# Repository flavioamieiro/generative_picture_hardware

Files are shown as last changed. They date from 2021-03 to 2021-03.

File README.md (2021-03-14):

This repository includes the design files for the hardware of the
Generative Picture project (this name will probably change). The
schematics and PCB layout are done in Kicad and all extra libraries
necessary to edit the project should be included here. If you find any
issues, please let me know.

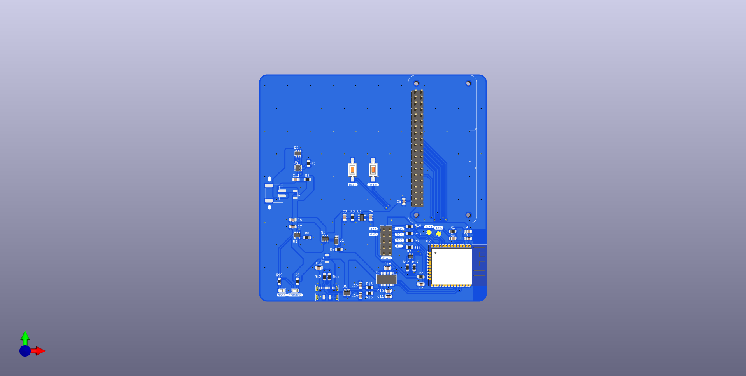
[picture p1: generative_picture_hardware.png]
generative picture board


This source describes Open Hardware and is licensed under the
CERN-OHL-S v2.  You may redistribute and modify this source and make
products using it under the terms of the CERN-OHL-S v2
(https://ohwr.org/cern_ohl_s_v2.txt).

This source is distributed WITHOUT ANY EXPRESS OR IMPLIED WARRANTY,
INCLUDING OF MERCHANTABILITY, SATISFACTORY QUALITY AND FITNESS FOR A
PARTICULAR PURPOSE. Please see the CERN-OHL-S v2 for applicable
conditions.

Source location:
https://github.com/flavioamieiro/generative_picture_hardware

As per CERN-OHL-S v2 section 4, should You produce hardware based on
this source, You must where practicable maintain the Source Location
visible on the external case of the Gizmo or other products you make
using this source.

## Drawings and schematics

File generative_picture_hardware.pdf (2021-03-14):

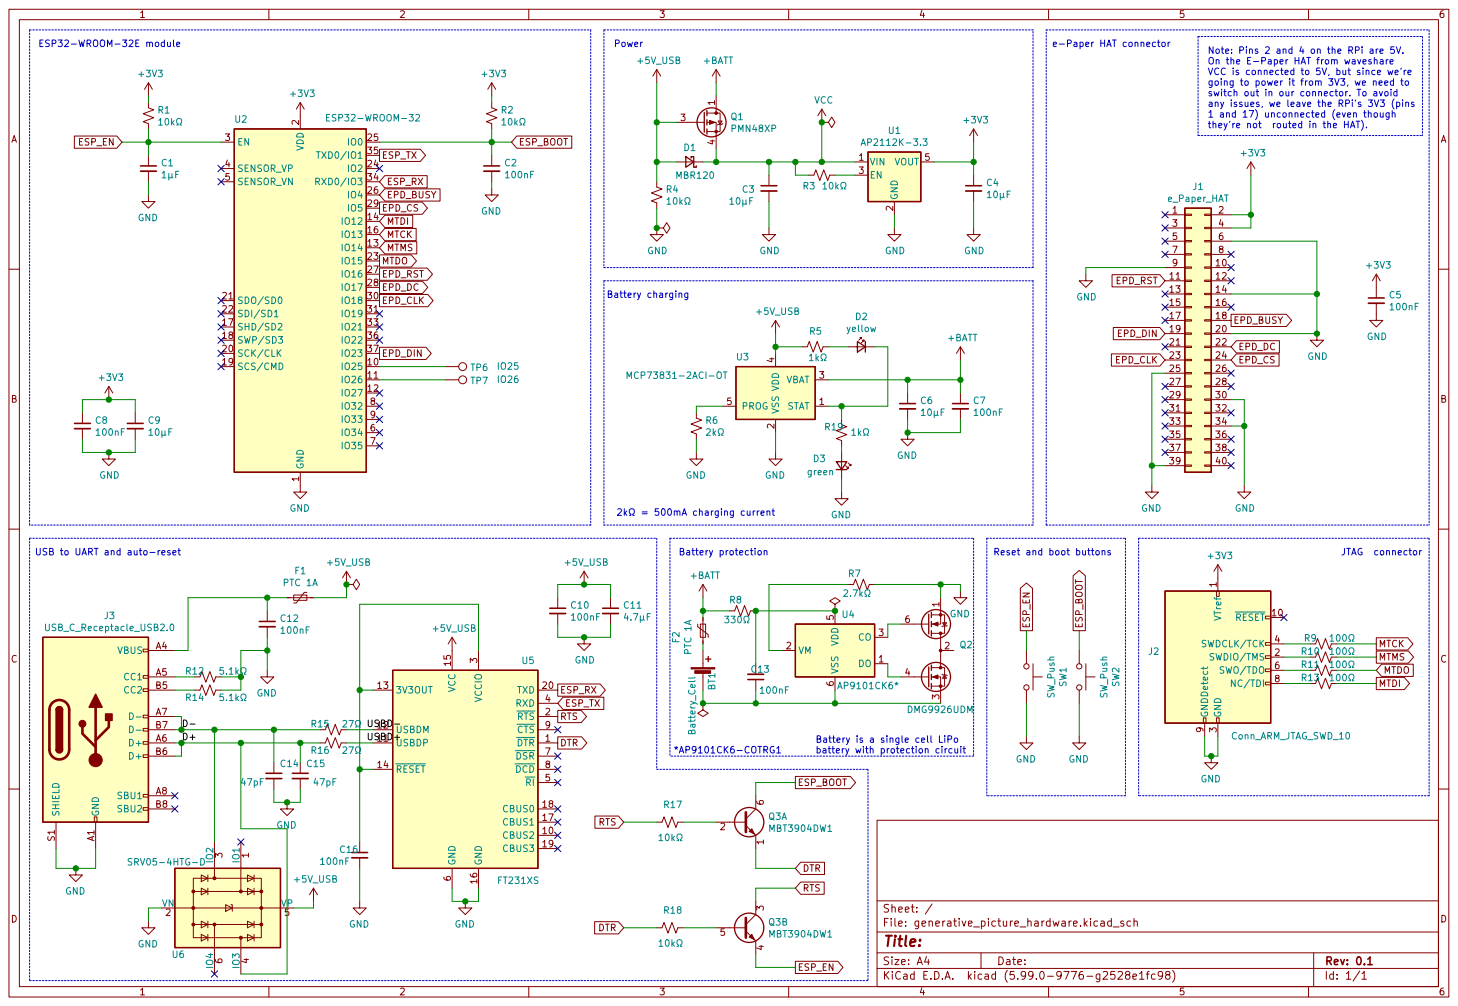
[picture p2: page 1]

any issues, we leave the RPi's 3V3 (pins
1 and 17) unconnected (even though

2 SCK/CLK 20 SDO/SD0 21 SDI/SD1 22

4 PROG 5 U3 MCP73831-2ACI-OT GND GND GND

3 SWDCLK/TCK 4 SWO/TDO 6 NC/TDI 8 GNDDetect 9

6 ~DSR 7 ~DCD 8 ~CTS 9 U5 FT231XS R15 þÿ27©

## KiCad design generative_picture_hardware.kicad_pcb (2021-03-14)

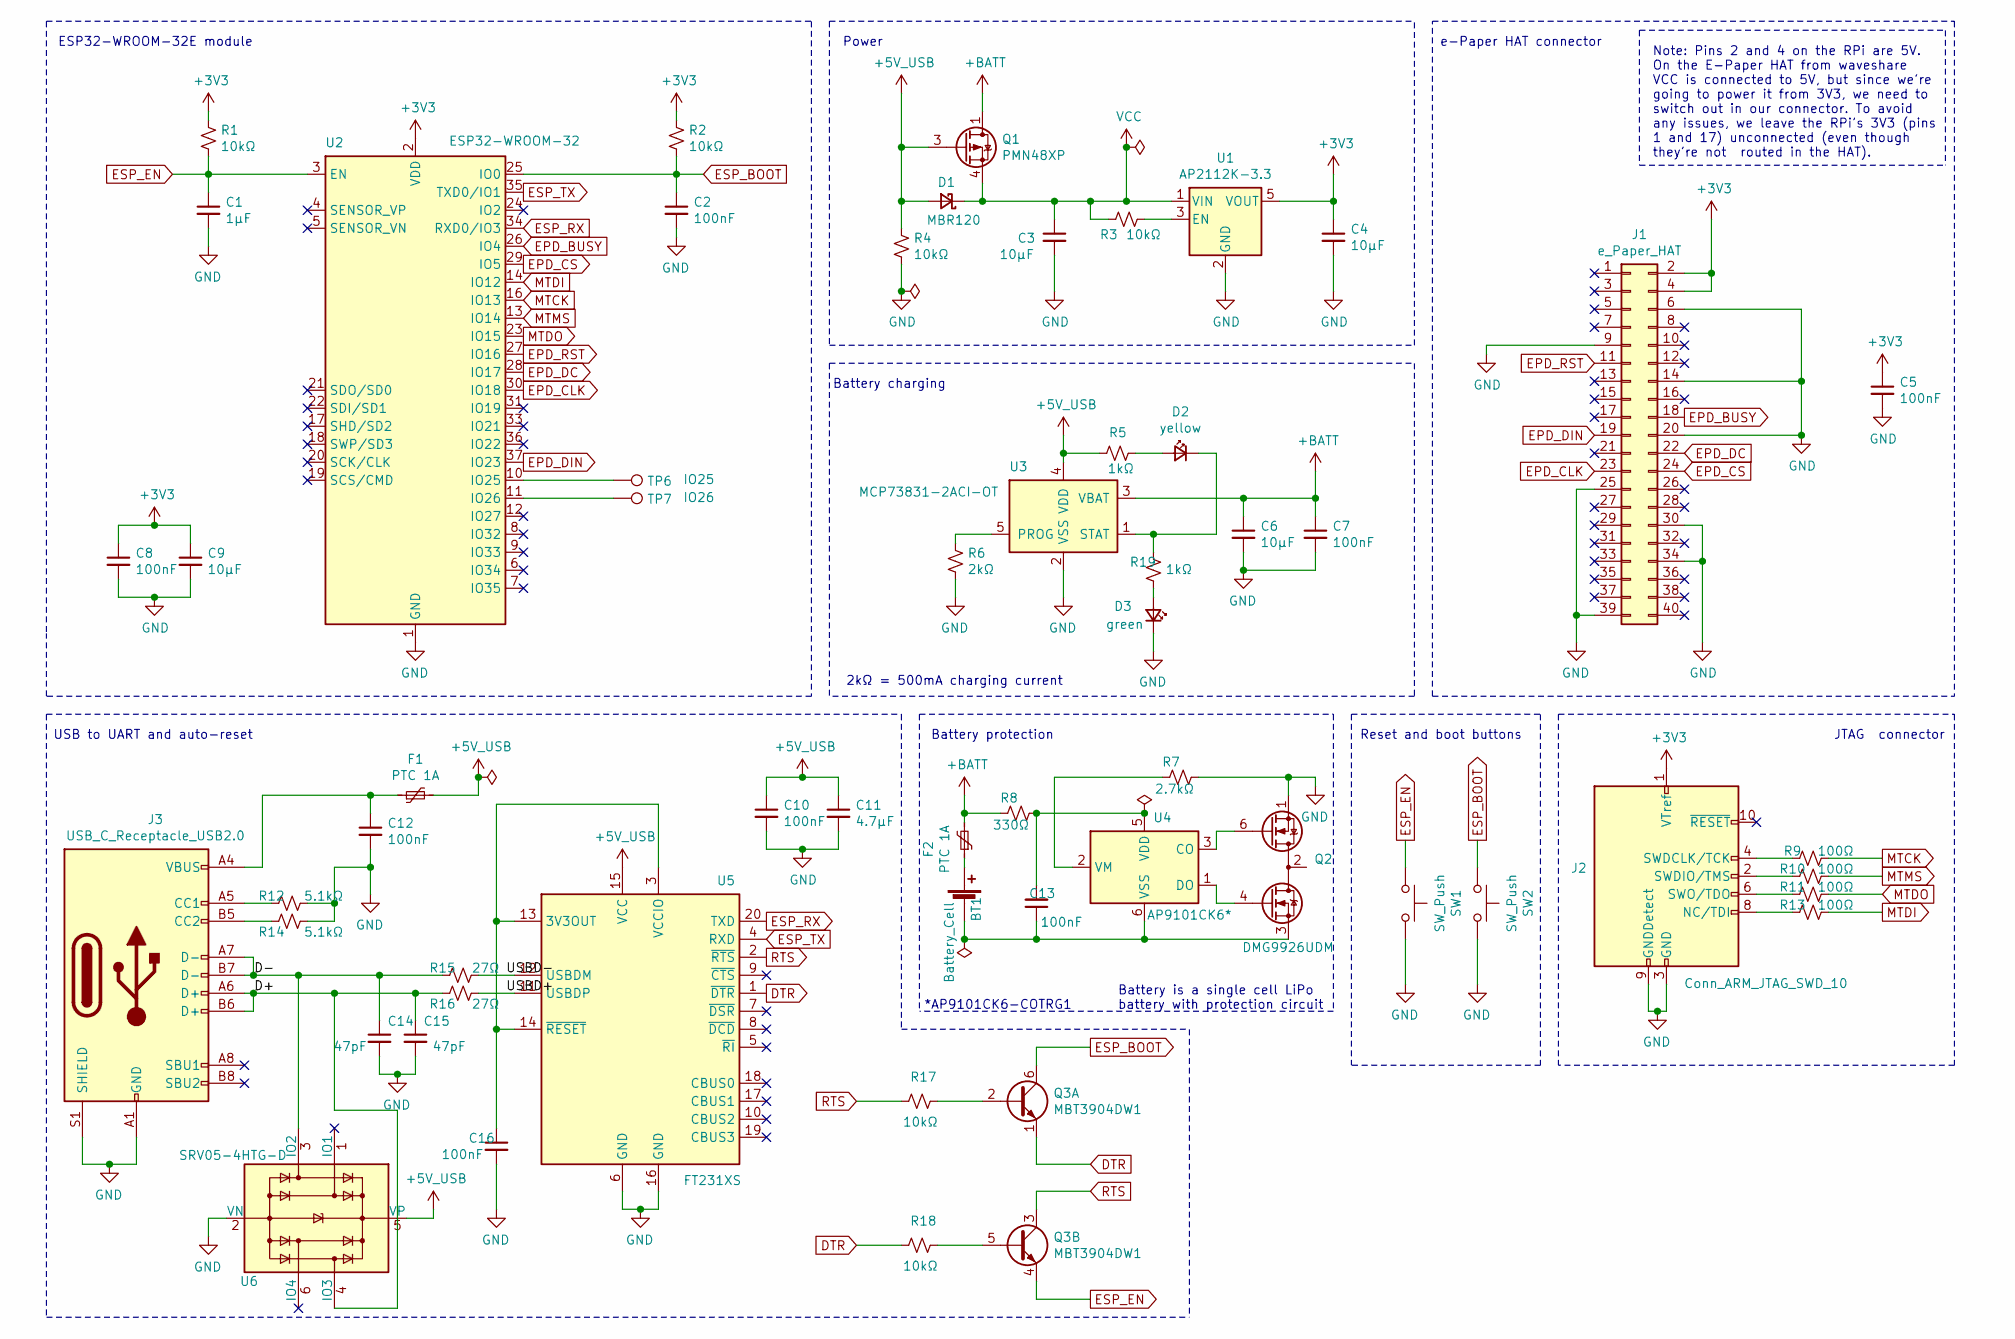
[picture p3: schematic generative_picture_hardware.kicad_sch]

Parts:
BT1: Battery_Cell; JST_PH_S2B-PH-SM4-TB_1x02-1MP_P2.00mm_Horizontal
C1: 1µF; C_0805_2012Metric_Pad1.18x1.45mm_HandSolder
C2, C5, C7, C8, C10, C12, C13, C16: 100nF; C_0805_2012Metric_Pad1.18x1.45mm_HandSolder
C3, C4, C6, C9: 10µF; C_0805_2012Metric_Pad1.18x1.45mm_HandSolder
C11: 4.7µF; C_0805_2012Metric_Pad1.18x1.45mm_HandSolder
C14, C15: 47pF; C_0805_2012Metric_Pad1.18x1.45mm_HandSolder
D1: MBR120; D_SOD-123
D2: yellow; LED_0805_2012Metric_Pad1.15x1.40mm_HandSolder
D3: green; LED_0805_2012Metric_Pad1.15x1.40mm_HandSolder
F1, F2: PTC 1A; Belfuse_0ZCJ
J1: e_Paper_HAT; e-Paper_display_HAT
J2: Conn_ARM_JTAG_SWD_10; PinHeader_2x05_P2.54mm_Vertical
J3: USB_C_Receptacle_USB2.0; USB_C_Receptacle_JAE_DX07S016JA1
Q1: PMN48XP; TSOP-6_1.65x3.05mm_P0.95mm
Q2: DMG9926UDM; SOT-23-6
Q3: MBT3904DW1; SOT-363_SC-70-6
R1, R2, R3, R4, R17, R18: 10kΩ; R_0805_2012Metric_Pad1.20x1.40mm_HandSolder
R5, R19: 1kΩ; R_0805_2012Metric_Pad1.20x1.40mm_HandSolder
R6: 2kΩ; R_0805_2012Metric_Pad1.20x1.40mm_HandSolder
R7: 2.7kΩ; R_0805_2012Metric_Pad1.20x1.40mm_HandSolder
R8: 330Ω; R_0805_2012Metric_Pad1.20x1.40mm_HandSolder
R9, R10, R11, R13: 100Ω; R_0805_2012Metric_Pad1.20x1.40mm_HandSolder
R12, R14: 5.1kΩ; R_0805_2012Metric_Pad1.20x1.40mm_HandSolder
R15, R16: 27Ω; R_0805_2012Metric_Pad1.20x1.40mm_HandSolder
SW1, SW2: SW_Push; SWITCH_TACTILE_CK_PTS636_SK43_SMTR_LFS
TP6: IO25; TestPoint_Pad_D2.0mm
TP7: IO26; TestPoint_Pad_D2.0mm
U1: AP2112K-3.3; SOT-23-5
U2: ESP32-WROOM-32
U3: MCP73831-2ACI-OT; SOT-23-5
U4: AP9101CK6*; SOT-23-6
U5: FT231XS; SSOP-20_3.9x8.7mm_P0.635mm
U6: SRV05-4HTG-D; SOT-23-6

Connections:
+3V3: C4.1, C5.1, C8.1, C9.1, J1.2, J1.4, J2.1 (VTref), R1.1, R2.1, U1.5 (VOUT), U2.2 (VDD)
+5V: C10.1, C11.1, D1.2 (A), F1.2, Q1.3 (G), R4.1, R5.1, U3.4 (VDD), U5.15 (VCC), U6.5 (VP)
+BATT: C6.1, C7.1, F2.2, Q1.1 (D), Q1.2 (D), Q1.5 (D), Q1.6 (D), R8.2, U3.3 (VBAT)
/D+: C15.1, J3.A6 (D+), J3.B6 (D+), R16.1, U6.4 (IO3)
/D-: C14.1, J3.A7 (D-), J3.B7 (D-), R15.1, U6.3 (IO2)
/USBD+: R16.2, U5.11 (USBDP)
/USBD-: R15.2, U5.12 (USBDM)
DTR: Q3.1 (E1), R18.2, U5.1 (~DTR)
EPD_BUSY: J1.18, U2.26 (IO4)
EPD_CLK: J1.23, U2.30 (IO18)
EPD_CS: J1.24, U2.29 (IO5)
EPD_DC: J1.22, U2.28 (IO17)
EPD_DIN: J1.19, U2.37 (IO23)
EPD_RST: J1.11, U2.27 (IO16)
ESP_BOOT: C2.1, Q3.6 (C1), R2.2, SW2.1, U2.25 (IO0)
ESP_EN: C1.1, Q3.4 (E2), R1.2, SW1.1, U2.3 (EN)
ESP_RX: U2.34 (RXD0/IO3), U5.20 (TXD)
ESP_TX: U2.35 (TXD0/IO1), U5.4 (RXD)
GND: C1.2, C2.2, C3.2, C4.2, C5.2, C6.2, C7.2, C8.2, C9.2, C10.2, C11.2, C12.2, C14.2, C15.2, C16.2, D3.1 (K), J1.6, J1.9, J1.14, J1.20, J1.25, J1.30, J1.34, J1.39, J2.3 (GND), J2.5 (GND), J2.9 (GNDDetect), J3.A1 (GND), J3.A12 (GND), J3.B1 (GND), J3.B12 (GND), J3.S1 (SHIELD), Q2.1 (D1), R4.2, R6.2, R7.1, R12.2, R14.2, SW1.2, SW2.2, U1.2 (GND), U2.1 (GND), U2.15 (GND), U2.38 (GND), U2.39 (GND), U3.2 (VSS), U5.6 (GND), U5.16 (GND), U6.2 (VN)
MTCK: R9.2, U2.16 (IO13)
MTDI: R13.2, U2.14 (IO12)
MTDO: R11.2, U2.23 (IO15)
MTMS: R10.2, U2.13 (IO14)
unnamed: BT1.1 (+), F2.1
unnamed: BT1.2 (-), C13.1, Q2.3 (S2), U4.6 (VSS)
unnamed: C12.1, F1.1, J3.A4 (VBUS), J3.A9 (VBUS), J3.B4 (VBUS), J3.B9 (VBUS)
unnamed: C13.2, R8.1, U4.5 (VDD)
unnamed: C16.1, U5.3 (VCCIO), U5.13 (3V3OUT), U5.14 (~RESET)
unnamed: D2.1 (K), R19.1, U3.1 (STAT)
unnamed: D2.2 (A), R5.2
unnamed: D3.2 (A), R19.2
unnamed: J2.2 (SWDIO/TMS), R10.1
unnamed: J2.4 (SWDCLK/TCK), R9.1
unnamed: J2.6 (SWO/TDO), R11.1
unnamed: J2.8 (NC/TDI), R13.1
unnamed: J3.A5 (CC1), R12.1
unnamed: J3.B5 (CC2), R14.1
unnamed: Q2.2 (S1/D2), Q2.5 (S1/D2)
unnamed: Q2.4 (G2), U4.1 (DO)
unnamed: Q2.6 (G1), U4.3 (CO)
unnamed: Q3.2 (B1), R17.1
unnamed: Q3.5 (B2), R18.1
unnamed: R3.2, U1.3 (EN)
unnamed: R6.1, U3.5 (PROG)
unnamed: R7.2, U4.2 (VM)
unnamed: TP6.1, U2.10 (IO25)
unnamed: TP7.1, U2.11 (IO26)
RTS: Q3.3 (C2), R17.2, U5.2 (~RTS)
VCC: C3.1, D1.1 (K), Q1.4 (S), R3.1, U1.1 (VIN)

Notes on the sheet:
ESP32-WROOM-32E module
USB to UART and auto-reset
Power
Battery charging
Battery protection
2kΩ = 500mA charging current
*AP9101CK6-COTRG1
Battery is a single cell LiPo battery with protection circuit
Reset and boot buttons
e-Paper HAT connector
Note: Pins 2 and 4 on the RPi are 5V. On the E-Paper HAT from waveshare VCC is connected to 5V, but since we're going to power it from 3V3, we need to switch out in our connector. To avoid any issues, we leave the RPi's 3V3 (pins 1 and 17) unconnected (even though they're not routed in the HAT).
JTAG connector

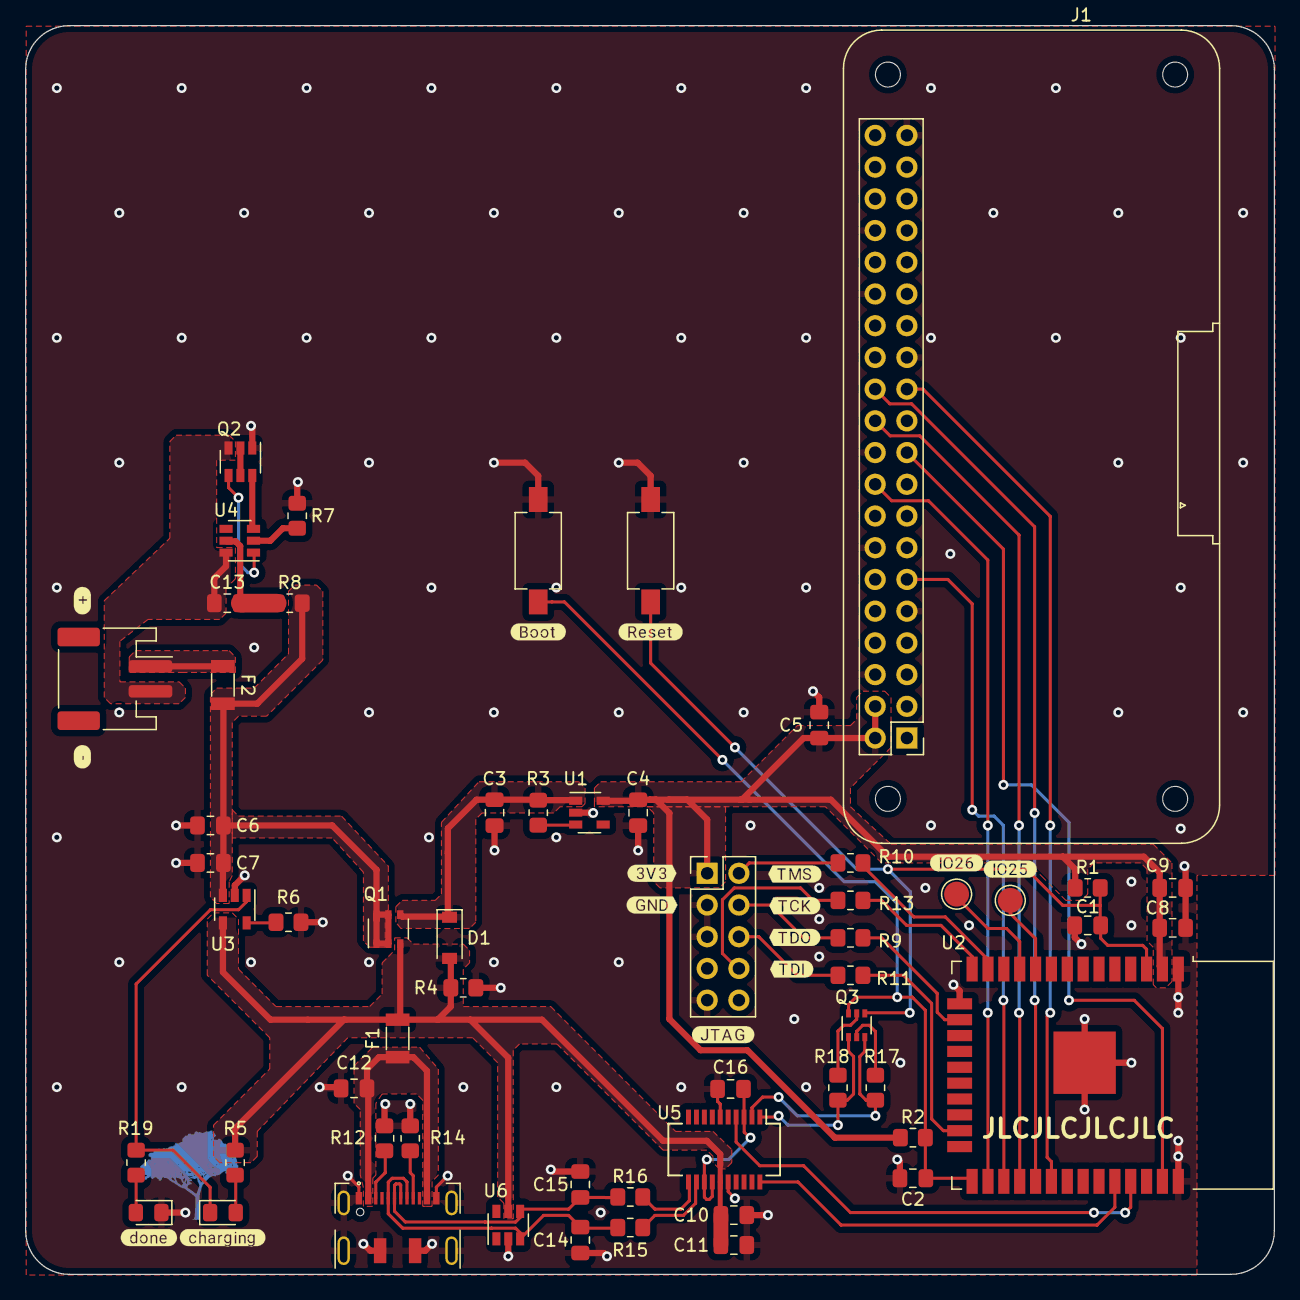
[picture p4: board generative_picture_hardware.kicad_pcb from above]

Board: 2 copper layers, 100.0 x 100.0 mm, 59 parts (0 on the bottom side), 49 nets.

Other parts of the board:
Ref**: Val**; url_bsilks
Ref**#2: Val**; ipe_logo

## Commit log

2021-01-23 Initial commit (empty kicad project)
    [generative_picture_hardware.kicad_pcb, generative_picture_hardware.kicad_sch]
2021-01-24 Start the schematics by connecting the HAT pins to the ESP32
    The VCC on the e-Paper HAT is connected to 5V[1], but we will power it from
    the 3V3 rails as I did in all my tests*. Because of that, we can't
    replicate the pinout of the raspberry Pi header exactly. Instead, we
    connect 3V3 to where 5V is on the Pi and leave the pins where the Pi has
    3V3 unconnected (even though they're not routed in the HAT).
    * The level shifter in the HAT (a TXS0108E[2]) takes from 1.65 to 5.5V on the
    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
    [generative_picture_hardware.kicad_sch]
2021-01-24 Adds JTAG connector
    I'm using 100Ω series resistors in the JTAG lines as per the reference
    design in the ESP32-WROOM-32 datasheet[1] (section 7).
    [1]: https://www.espressif.com/sites/default/files/documentation/esp32-wroom-32_datasheet_en.pdf
    [generative_picture_hardware.kicad_sch]
2021-01-25 Adds minimal circuit around the ESP32 module
    [generative_picture_hardware.kicad_sch]
2021-02-01 Adds USB to UART converter and auto-reset circuit
    I'm using the FTDI FT231XS USB to UART converter IC. There's also a
    TVS diode array for ESD protection, which might be overkill but I
    decided to add it anyways.
    [generative_picture_hardware.kicad_sch]
2021-02-01 Adds boot button and fixes global label directions
    [generative_picture_hardware.kicad_sch]
2021-02-01 Adds LiPo charging circuit
    Uses the MCP73831 to charge a single cell LiPo battery that should
    have undervoltage protection builtin[1]
    [1]: Such as https://www.adafruit.com/product/328
    [generative_picture_hardware.kicad_sch]
2021-02-01 Adds LDO regulator circuit
    This circuit uses a p-channel MOSFET to switch the power supply to the
    regulator from battery to USB when the cable is plugged in[1].
    [1]: https://www.youtube.com/watch?v=GRd9uTwg7r4
    [generative_picture_hardware.kicad_sch]
2021-02-01 Adds annotations and fixes small issues after ERC
    [generative_picture_hardware.kicad_sch]
2021-02-03 Reorganizes auto-reset circuit
    This makes it more clear and better aligned.
    [generative_picture_hardware.kicad_sch]
2021-02-03 Adds battery protection circuit with AP9101
    [generative_picture_hardware.kicad_sch]
2021-02-03 Adds test points to some of the remaining GPIO pins of the ESP32
    [generative_picture_hardware.kicad_sch]
2021-02-05 Adds a second LED to indicate the charging is complete and assigns some footprints
    As per table 5-1 in the MCP73831 datasheet[1], the STAT pin is low while
    charging, high when charge is complete and high impedance when the IC is
    shutdown or there is no battery present:
    +----------+--------+
    | Charging |STAT pin|
    +----------+--------+
    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
    [generative_picture_hardware.kicad_sch]
2021-02-05 Adds footprint for Bourns MF-NSHT PTC resettable Fuse
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2021-02-08 Fixes e-paper HAT connector footprint
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2021-02-08 Adds labels to USB data lines to allow for routing as differential pairs
    [generative_picture_hardware.kicad_sch]
2021-02-08 Changes pins on the TVS diodes to make it easier to route
    [generative_picture_hardware.kicad_sch]
2021-02-08 Removes some unused test points
    They have no immediate use and wouldn't be trivial to route.
    [generative_picture_hardware.kicad_sch]
2021-02-08 Fixes small issues with the e-Paper hat connector footprint
    There courtyard was self-intersecting, so I removed the FFC connector's
    courtyard (since it's actually raised above the PCB on the connected
    board). The silkscreen and fab layers for the pin header were also
    misaligned.
2021-02-08 Fixes silkscreen overlaping pads in the tactile switch footprint
2021-02-10 Adds first (really) rough layout for the PCB
    There is some really bad routing and the GND is not completely routed.
    [generative_picture_hardware.kicad_pcb]
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2021-02-10 Routes missing boot and reset lines from reset circuit
    [generative_picture_hardware.kicad_pcb]
2021-02-10 Routes (temporarily) some of the missing 3v3 lines
    [generative_picture_hardware.kicad_pcb]
2021-02-15 Fixes the size for the HAT mounting holes
    The mounting holes on the HAT are M2.5 but the standoffs are M2.
    [generative_picture_hardware.kicad_pcb]
2021-02-15 Fixes clearance between Vbus track and usb connector mounting hole
    This will probably need to be reworked once I increase the thickness for
    the power lines.
    [generative_picture_hardware.kicad_pcb]
2021-02-15 Routes all ground without relying on the top copper fill
    [generative_picture_hardware.kicad_pcb]
2021-02-15 Deletes all tracks and (very) roughly repositions groups of components
    [generative_picture_hardware.kicad_pcb]
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2021-02-15 Removes some more test points for GPIO pins
    I don't really have any use planned for them. Two should be plenty if
    needed at all.
    [generative_picture_hardware.kicad_sch]
2021-02-15 Reroutes the components that were left (except for GND)
    [generative_picture_hardware.kicad_pcb]
2021-02-15 Routes all GND without relying on front copper fill
    [generative_picture_hardware.kicad_pcb]
2021-02-17 Organizes silkscreen a bit
    This is not final, but it removes the silkscreen related DRC errors.
    [generative_picture_hardware.kicad_pcb]
2021-02-17 Fixes error in the tracks out of the USB plug
    [generative_picture_hardware.kicad_pcb]
2021-02-17 moves JTAG connector so we have more space for the labels
    [generative_picture_hardware.kicad_pcb]
2021-02-17 Removes battery test points and adds labels to JTAG connector
    [generative_picture_hardware.kicad_pcb, generative_picture_hardware.kicad_sch]
2021-02-17 Removes copper fills from below the antenna keepout area
    [generative_picture_hardware.kicad_pcb]
2021-02-17 Adds some vias to stitch the bottom and top ground planes
    [generative_picture_hardware.kicad_pcb]
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2021-02-19 Brings FTDI chip closer to the usb plug
    This shortens the differential pair track lenghts.
    [generative_picture_hardware.kicad_pcb]
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2021-02-19 Uses copper fills for the battery power traces
    [generative_picture_hardware.kicad_pcb]
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2021-02-19 Uses copper fill for VCC path to regulator
    [generative_picture_hardware.kicad_pcb]
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2021-02-20 Adjusts some of the interactions between pads and copper fills
    [generative_picture_hardware.kicad_pcb]
2021-02-20 Adds JLCPCB order number placeholder adjusts silkscreen some more
    [generative_picture_hardware.kicad_pcb]
2021-02-20 Changes PTC footprint
    It's still 1206 but with slightly wider pads.
    [generative_picture_hardware.kicad_pcb, generative_picture_hardware.kicad_sch]
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2021-03-14 Switches C8 and C9 placement in the layout
    [generative_picture_hardware.kicad_pcb, generative_picture_hardware.kicad_sch]
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2021-03-25 Adds Manufacturer Part Number to some components
    This helps building a more useful BOM. I left out the resistors and
    capacitors as the specific part is not so important.
    [generative_picture_hardware.kicad_sch]
